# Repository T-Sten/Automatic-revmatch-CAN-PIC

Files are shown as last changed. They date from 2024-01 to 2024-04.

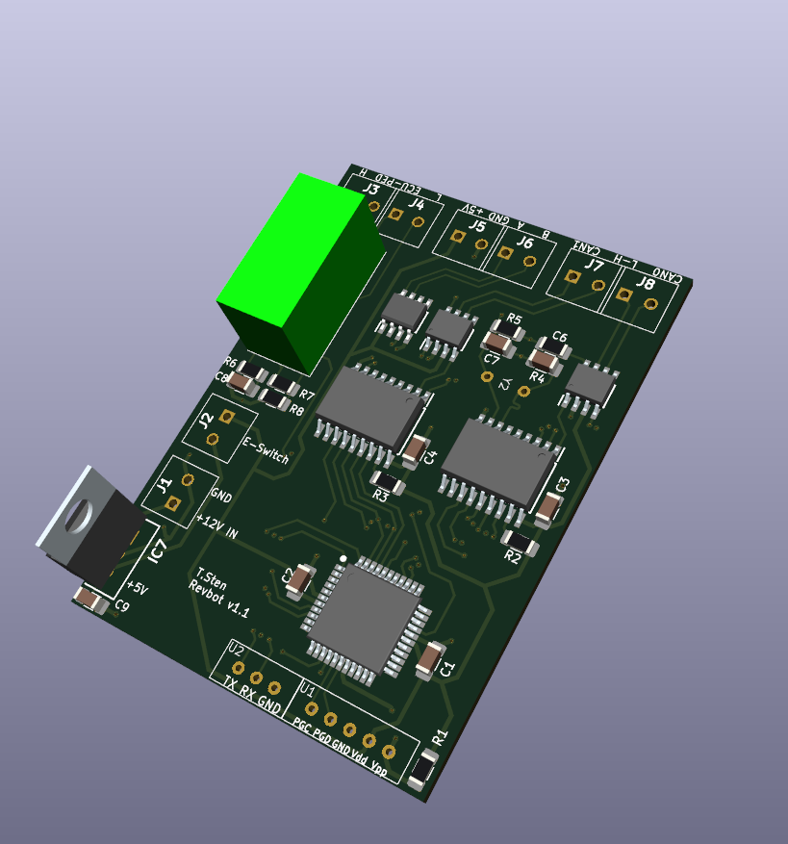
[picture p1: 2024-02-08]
PCB_3D.png

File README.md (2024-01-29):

# OPEL-automatic-revmatch-project

Hi! This is a project on creating a device that by plugging into a car's CAN buses and thottle pedal signals, is able to match the
engine RPMs of the lower gear to the wheel speed during a downshift, known as "Revmatching".
The operation of the device is controlled by a PIC16F877A MCU from Microchip.

### Basic idea
The basic idea is as follows: 
Steering wheel button pressed -> Wait for clutch disengagement -> Raise engine RPM to match the lower gear at the current speed and keep it there
-> Wait for clutch engagement -> Stop.

### CAN bus data
From the 3 CAN buses of my 2005 OPEL Vectra C we are interested in 2 of them: 95kbps low speed bus from where driver input can be read 
(such as steering wheel buttons for activating revmatching mode) and the 500kbps bus from where vehicle telematics data can be read
(such as engine RPM, vehicle speed, clucth state etc.). The vehicles CAN buses will be interfaced with a MCP2515 CAN controller IC
and a MCP2551 CAN transciever IC for each of the 2 buses.

### Controlling the throttle
Throttle is controlled by tapping into the (2) throttle pedal potentiometer output wires and with a signal relay we can disconnect
the thottle pedal outputs and start driving the signal voltage with a capacitor smooothed PWM signal to be interpreted by the ECU.
Throttle value is calculated using PID control.

### Additional features
Additional features of the device include displaying current gear on the dashboard with a 7-segment led and a led array for the current RPM. 
These are driven by 2 8-bit shift registers that are interfaced by the MCU with a single differential pair using a RS485 transciever.
Another feature is "welcome actions" where upon unlocking the car doors, horn is briefly activated 3 times
and high beams flashed. This is done by replicating driver input by sending a CAN frame that corresponds to the activation of their driver controls.

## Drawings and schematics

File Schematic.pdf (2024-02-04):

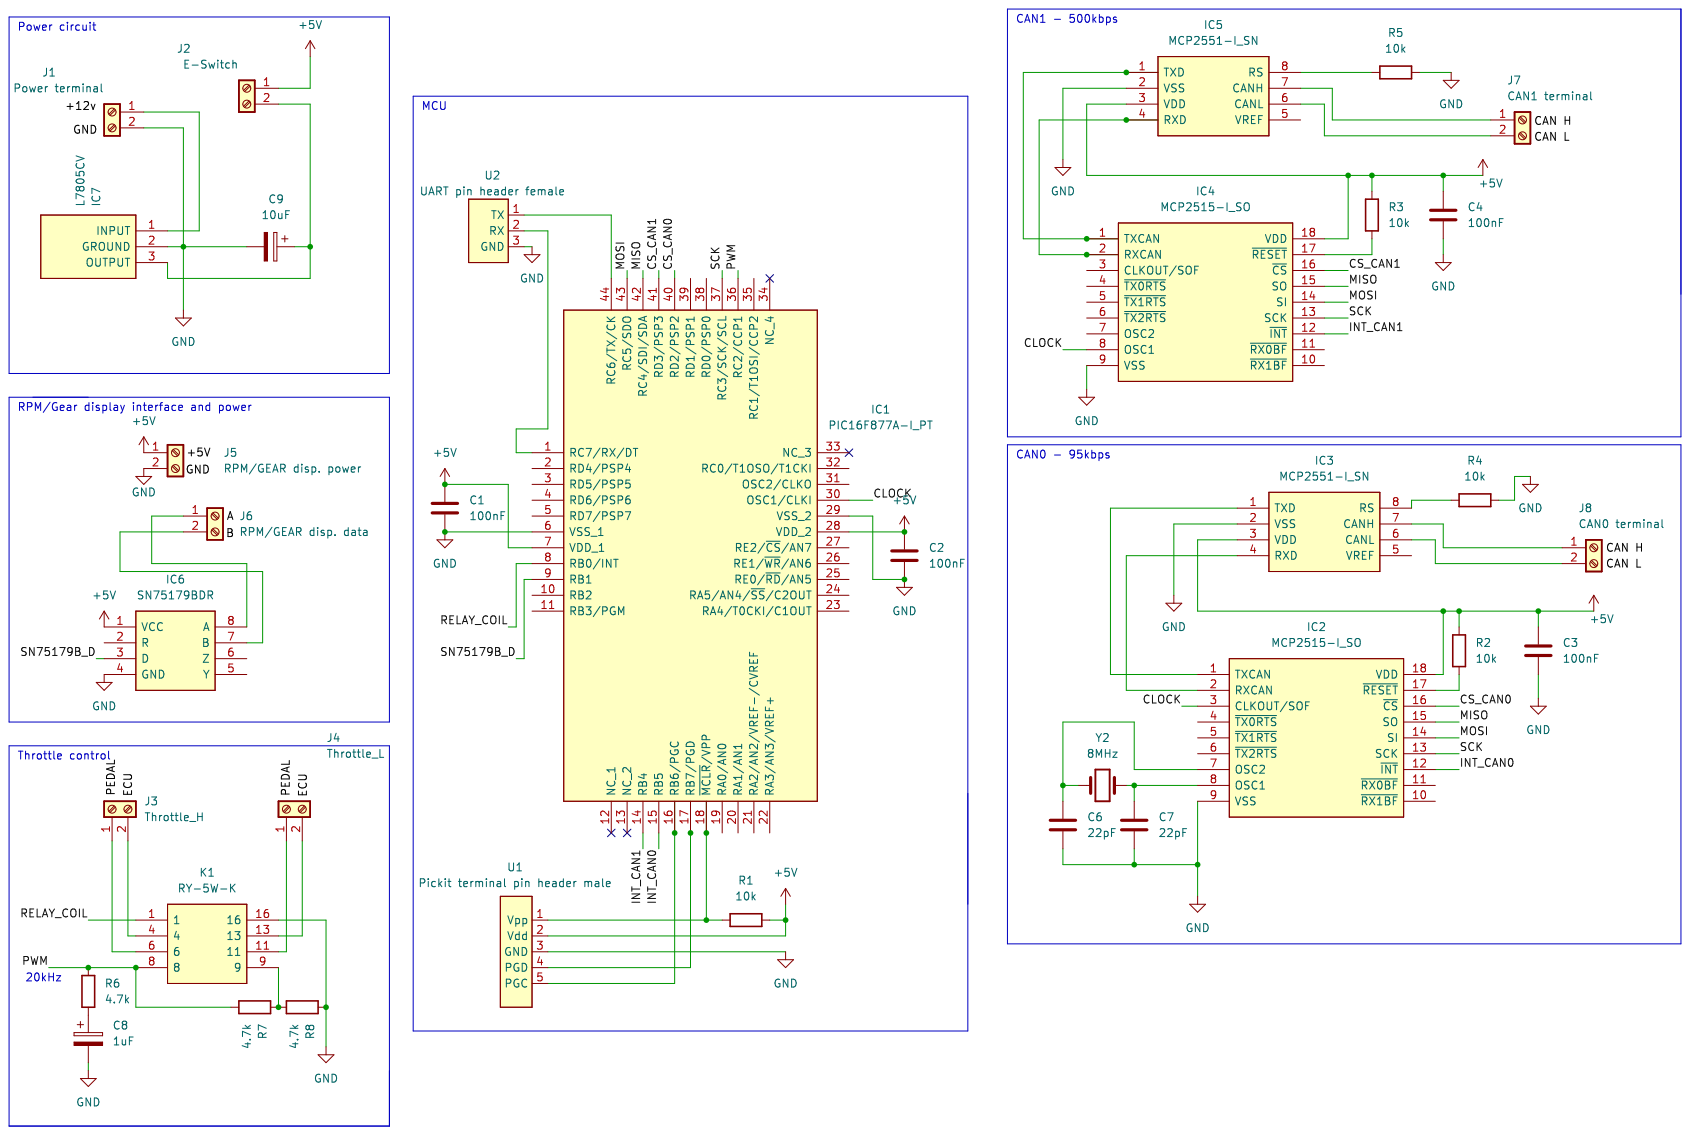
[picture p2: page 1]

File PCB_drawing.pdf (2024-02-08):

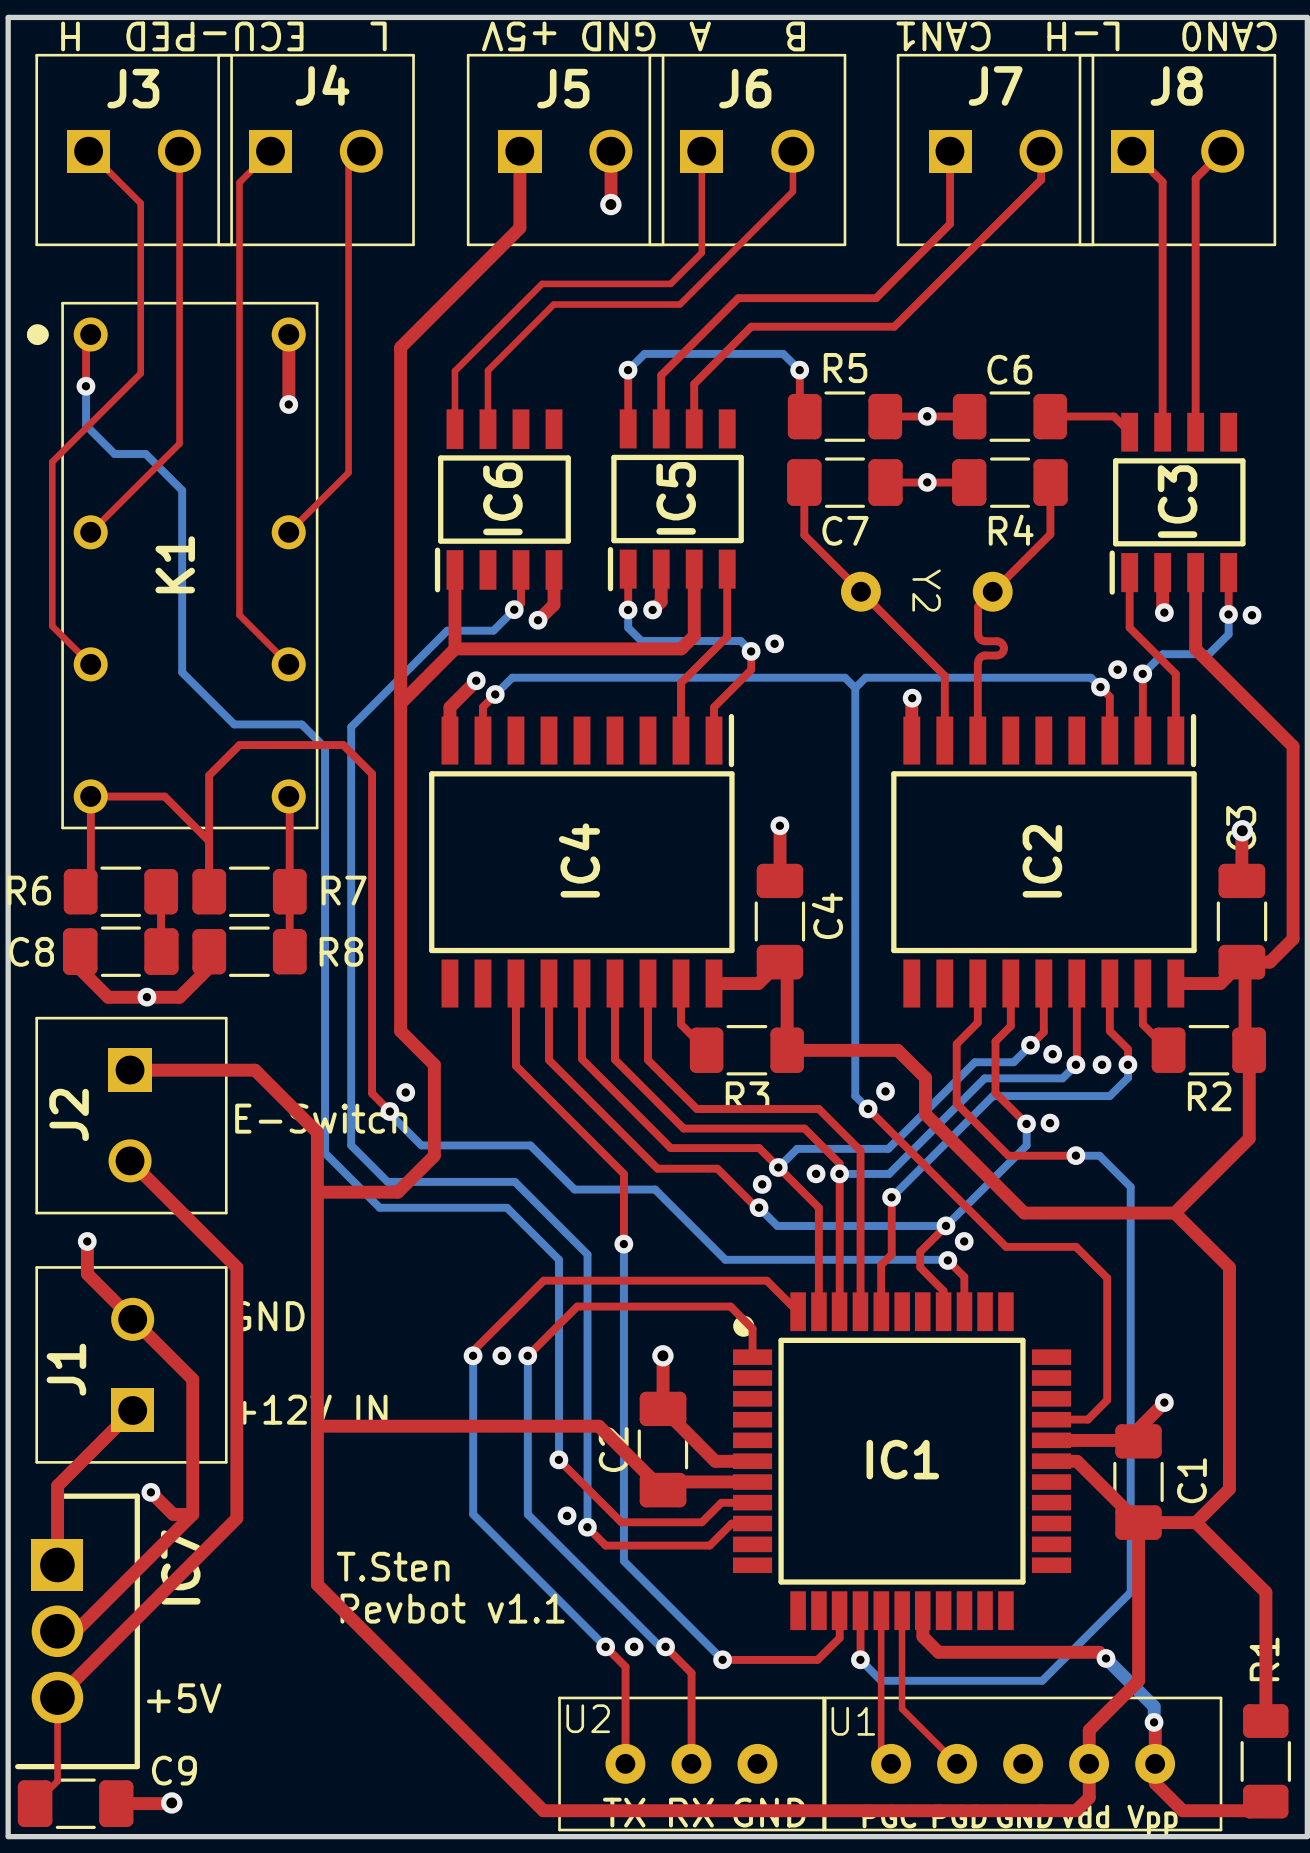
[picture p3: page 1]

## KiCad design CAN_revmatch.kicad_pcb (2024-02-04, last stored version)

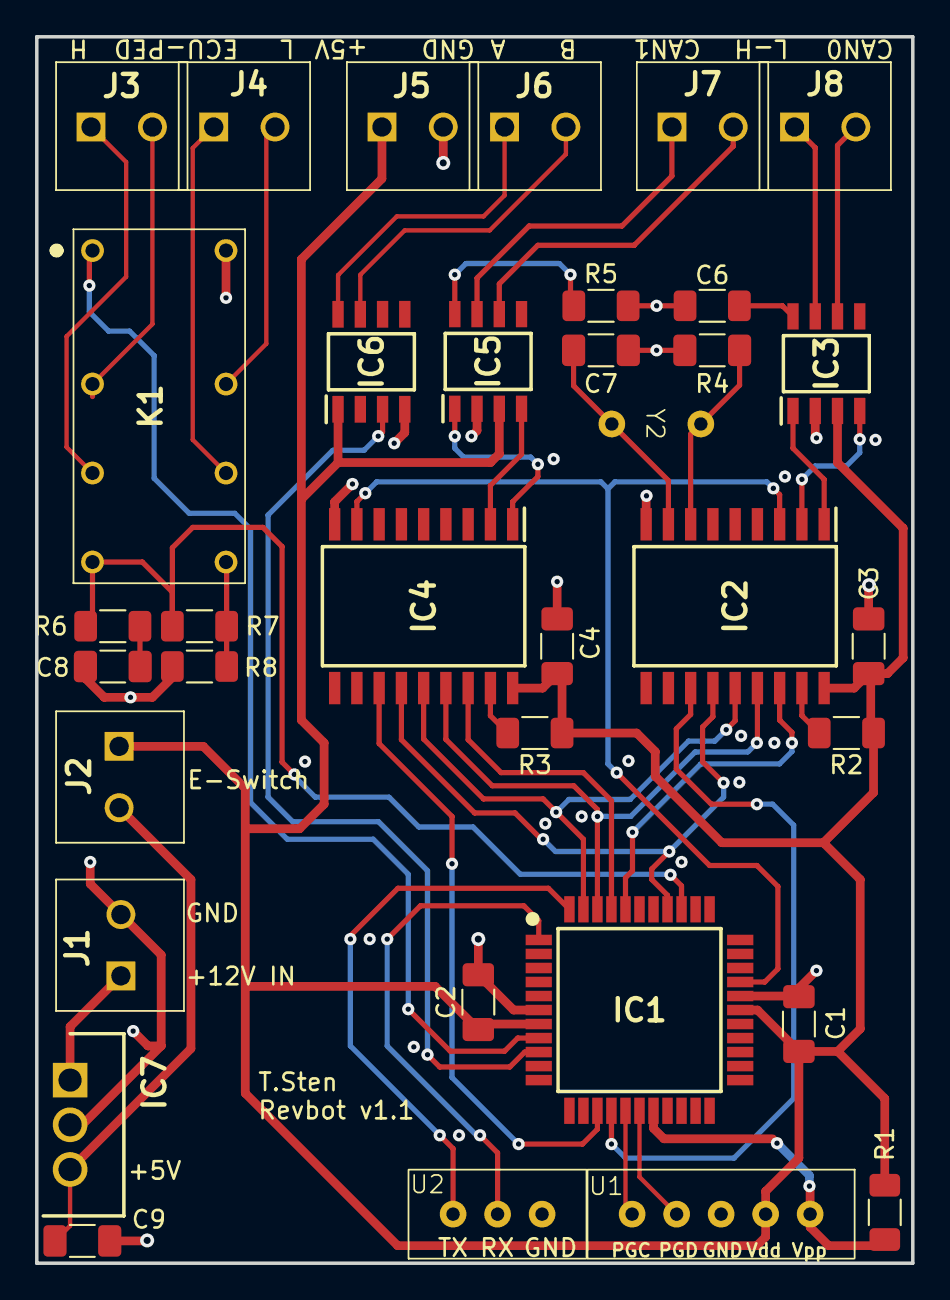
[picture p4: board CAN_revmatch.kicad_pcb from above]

Board: 4 copper layers, 50.0 x 70.0 mm, 35 parts (0 on the bottom side), 42 nets.

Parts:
C1, C2, C3, C4: 100nF; C_1206_3216Metric_Pad1.33x1.80mm_HandSolder
C6, C7: 22pF; C_1206_3216Metric_Pad1.33x1.80mm_HandSolder
C8: 1uF; C_1206_3216Metric_Pad1.33x1.80mm_HandSolder
C9: 10uF; C_1206_3216Metric_Pad1.33x1.80mm_HandSolder
IC1: PIC16F877A-I_PT; PIC16F877A-SOIC-44pin
IC2, IC4: MCP2515-I_SO; MCP2515_SOIC
IC3, IC5: MCP2551-I_SN; MCP2551_SOIC
IC6: SN75179BDR; Transciever_SN75179BDR
IC7: L7805CV
J1: Power terminal; 1888807
J2: E-Switch; 1888807
J3: Throttle_H; 1888807
J4: Throttle_L; 1888807
J5: RPM/GEAR disp. power; 1888807
J6: RPM/GEAR disp. data; 1888807
J7: CAN1 terminal; 1888807
J8: CAN0 terminal; 1888807
K1: RY-5W-K; RY5WK
R1, R2, R3, R4, R5: 10k; R_1206_3216Metric_Pad1.30x1.75mm_HandSolder
R6, R7, R8: 4.7k; R_1206_3216Metric_Pad1.30x1.75mm_HandSolder
U1: Pickit terminal pin header male; PICKIT_terminal
U2: UART pin header female; UART_terminal
Y2: 8MHz; KIDE

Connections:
+5V: C1.1, C2.1, C3.1, C4.1, IC1.7 (VDD_1), IC1.28 (VDD_2), IC2.18 (VDD), IC3.3 (VDD), IC4.18 (VDD), IC5.3 (VDD), IC6.1 (VCC), J2.1, J5.1, R1.2, R2.1, R3.1, U1.2 (Vdd)
/CLOCK: IC1.30 (OSC1/CLKI), IC2.3 (CLKOUT/SOF), IC4.8 (OSC1)
/CS_CAN0: IC1.40 (RD2/PSP2), IC2.16 (~CS)
/CS_CAN1: IC1.41 (RD3/PSP3), IC4.16 (~CS)
/INT_CAN0: IC1.15 (RB5), IC2.12 (~INT)
/INT_CAN1: IC1.14 (RB4), IC4.12 (~INT)
/MISO: IC1.42 (RC4/SDI/SDA), IC2.15 (SO), IC4.15 (SO)
/MOSI: IC1.43 (RC5/SDO), IC2.14 (SI), IC4.14 (SI)
/PWM: IC1.36 (RC2/CCP1), K1.8, R6.1, R7.2
/RELAY_COIL: IC1.8 (RB0/INT), K1.1
/SCK: IC1.37 (RC3/SCK/SCL), IC2.13 (SCK), IC4.13 (SCK)
/SN75179B_D: IC1.9 (RB1), IC6.3 (D)
GND: C1.2, C2.2, C3.2, C4.2, C6.2, C7.2, C8.2, C9.2, IC1.6 (VSS_1), IC1.29 (VSS_2), IC2.9 (VSS), IC3.2 (VSS), IC4.9 (VSS), IC5.2 (VSS), IC6.4 (GND), IC7.2 (GROUND), J1.2, J5.2, K1.16, R4.2, R5.2, R8.1, U1.3 (GND), U2.3 (GND)
unnamed: C8.1, R6.2
unnamed: IC1.16 (RB6/PGC), U1.5 (PGC)
unnamed: IC1.17 (RB7/PGD), U1.4 (PGD)
unnamed: IC1.44 (RC6/TX/CK), U2.1 (TX)
unnamed: IC1.1 (RC7/RX/DT), U2.2 (RX)
unnamed: IC1.18 (~MCLR/VPP), R1.1, U1.1 (Vpp)
unnamed: C7.1, IC2.8 (OSC1), Y2.2
unnamed: C6.1, IC2.7 (OSC2), Y2.1
unnamed: IC2.2 (RXCAN), IC3.4 (RXD)
unnamed: IC2.1 (TXCAN), IC3.1 (TXD)
unnamed: IC2.17 (~RESET), R2.2
unnamed: IC3.7 (CANH), J8.1
unnamed: IC3.6 (CANL), J8.2
unnamed: IC3.8 (RS), R4.1
unnamed: IC4.2 (RXCAN), IC5.4 (RXD)
unnamed: IC4.1 (TXCAN), IC5.1 (TXD)
unnamed: IC4.17 (~RESET), R3.2
unnamed: IC5.7 (CANH), J7.1
unnamed: IC5.6 (CANL), J7.2
unnamed: IC5.8 (RS), R5.1
unnamed: IC6.8 (A), J6.1
unnamed: IC6.7 (B), J6.2
unnamed: IC7.1 (INPUT), J1.1
unnamed: C9.1, IC7.3 (OUTPUT), J2.2
unnamed: J3.1, K1.6
unnamed: J3.2, K1.4
unnamed: J4.1, K1.11
unnamed: J4.2, K1.13
unnamed: K1.9, R7.1, R8.2

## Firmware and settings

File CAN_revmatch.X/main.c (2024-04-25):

/*
 * CAN revmatch PIC16F OPEL Vectra C
 * 
 * File:   main.c
 * Author: Tom Stenvall
 *
 * Created on January 2, 2024, 4:30 PM
 */

#include <xc.h>


#include "config.h"

#include <stdlib.h>
#include <string.h>
//#include <stdio.h> //FOR TESTING (SPRINTF)

#include "spi.h"
#include "mcp2515.h"
#include "PID.h"
#include "UART.h"
#include "dash.h"

#define _XTAL_FREQ 8000000 //"CAN0" MCP2515 SQWOUT will drive the PIC16F877A clock

//HIGH SPEED (BRGH = 1) SPBRG = (Fosc / (16 * BAUDRATE)) - 1
#define SPBRG 4 //100000

#define UART_HIGHSPEED 1

#define RELAY PORTBbits.RB0
#define CAN1_INT PORTBbits.RB4
#define CAN0_INT PORTBbits.RB5

#define SERIAL_BUFFER_SIZE 32

//CAN0 IDs
#define SWHEEL_ID 0x175
#define CENTRLOCKING_ID 0x135
#define PARKSENSOR_ID 0x430

//CAN1 IDs
#define RPM_ID 0x110
#define SPEED_ID 0x410
#define CLUTCH_ID 0x300

/*Good PID values
P 0.06
I 0.00001
D 3.5
*/


//Minimum gear to allow revmatch to
#define MIN_GEAR 2
#define MAX_RPM 5000

#define PWM_DUTY CCPR1L

//Parses can data to global variables and sets driver input flags
void CAN0_ID_handler(Can_frame*);
void CAN1_ID_handler(Can_frame*);

//For interfacing with PC GUI app
void serial_sendCanFrame(uint8_t bus, Can_frame* frame);
void serial_sendConsoleMessage(char *string);
void serial_sendPIDData(uint16_t throttle, uint16_t targetRpm, int16_t *components);
void serial_finishPIDData();
void serial_sendPIDConfig(uint8_t *bytes);

//Sets P, I, D values from the EEPROM
void PID_ini_from_eeprom();

//Estimates current gear from the current speed and RPM global variables,
//returns current gear or 0 for no match
uint8_t get_gear(); 

//Calculates target RPM for next lower gear, current gear as input parameter. 
//Gets current speed from global variable.
uint16_t get_next_target_rpm(uint8_t current_gear);

//PID control for the throttle, returns PWM duty cycle that meets the 1-3.6V HIGH pedal signal
uint8_t get_throttle_pwm(uint16_t target_rpm);

//CAN action sequences, these are all BLOCKING FUNCTIONS!!
void gong(); //Makes a short beep from the instrument cluster
void welcome_action(); //Shortly honks the horn 3 times, turns on highbeams for 2 seconds
void mirror_fold(uint8_t pos); //Folds the mirror up or down for reversing

//Sets idle filters
void CAN_idle_filters();

//For validating of can frame data and serial commands, returns 1 if data is same
uint8_t compareData(uint8_t data_1[],uint8_t data_2[], uint8_t size);


enum MODE{
    IDLE,
    WAIT_CLUTCH,
    REVMATCH,
};

//Serial commands from GUI app
enum serial_command{
    PID_SNIFF_SET,
    SEND,
    FRAME_DUMP_SET,
    ID_DUMP_SET,
    FILTER_SNIFF_START,
    FILTER_SNIFF_END,
    THROTTLE,
    PID_TEST_START,
    PID_TEST_END,
    PID_CONFIG_SET,
    PID_CONFIG_READ
};

//Serial message type to GUI app
typedef enum{
    CANFRAME,
    CONSOLE,
    PID_DATA,
    PID_DATA_END,
    PID_CONFIG
}SERIAL_MESSAGE;

//Tasks set by the GUI app
struct serialTasks{
    uint8_t can_dump_can0 :1;
    uint8_t can_dump_can1 :1;
    
    uint8_t can_sniff :1;
    uint8_t id_dump_can0 : 1;
    uint8_t id_dump_can1 : 1;
    
    uint8_t PID_sniff: 1;
    uint8_t PID_test: 1;
    uint16_t PID_test_targetRpm;
};

//Serial buffer struct
struct serial{
    union{
        struct{
            char sof[3];
            uint8_t len;
            uint8_t command;
            uint8_t data[SERIAL_BUFFER_SIZE - 5];
        };
        uint8_t buffer[SERIAL_BUFFER_SIZE];
    };
    uint8_t received_n;
    uint8_t overflow;
};

union driver_input_flags{
    struct{
        uint8_t sWheelUp : 1;
        uint8_t sWheelDown : 1;
        uint8_t doorsUnlocked :1;
    };
    uint8_t all;  
};

struct modeTasks{
    uint8_t multipleRevMatch : 1;
};

enum MODE mode = IDLE;
union driver_input_flags driverInputFlags;
struct modeTasks modeTasks;
struct serial serial;
struct serialTasks serialTasks;
const char SOF[3] = {'S', 'O', 'F'}; //This is indicates the start of a serial frame to and from the GUI app

uint32_t millis = 0, last_ledsUpdate = 0, last_7segUpdate = 0;

uint16_t current_rpm = 0;
uint8_t clutch_state, current_speed, current_gear;
uint8_t last_gear;

uint8_t dashCleared = 0;

//Create can instances and pointers
Mcp2515 can_0;
Mcp2515 can_1;
Mcp2515* can0 = &can_0;
Mcp2515* can1 = &can_1;

void __interrupt() isr(){
    
    if(CCP2IF){
        CCP2IF = 0;
        millis++;
    }
    
    //Reads UART
    if(RCIF){
        
        if(serial.received_n >= SERIAL_BUFFER_SIZE-2){
            serial.overflow = 1;
            serial.received_n = 0;
        }
        
        serial.buffer[serial.received_n] = RCREG;
        

        if(serial.received_n < 3 && serial.sof[serial.received_n] != SOF[serial.received_n]){
            serial.received_n = 0;
        }
        else{
            serial.received_n++;
        }


        RCIF = 0;            
    }
}

void main(void) {
    
    
    TRISBbits.TRISB0 = 0; //Relay output    
    RELAY = 0;
    
    SPI_ini(SPI_SPEED_FOSC_4);
    
    UART_ini(SPBRG, UART_HIGHSPEED);
    
    TRISBbits.TRISB4 = 1;
    OPTION_REGbits.nRBPU = 0;//Enable pullups
    
    MCP2515_attach(can0, PORT_D, 2);
    MCP2515_attach(can1, PORT_D, 3);
    MCP2515_ini(can0, BUS_SPEED_33KBPS, 1);
    MCP2515_ini(can1, BUS_SPEED_500KBPS, 1);
    
    MCP2515_setmode(can0, MODE_CONFIGURE);
    MCP2515_setmode(can1, MODE_CONFIGURE);
    
    //Set normal operation filters
    CAN_idle_filters();
    
    //Enable specific interrupts to drive the MCP2515 interrupt pin
    MCP2515_interrupt_enable(can0, RX0I | RX1I);   //Interrupts on reception to receive buffer 0 and 1, will wake up and start oscillator on bus activity
    MCP2515_interrupt_enable(can1, RX0I | RX1I);   //Interrupt on reception to receive buffer 0
    
    MCP2515_setmode(can0, MODE_NORMAL);
    MCP2515_setmode(can1, MODE_NORMAL);
    
    MCP2515_setclkout(can0, CLKOUT_1);
    MCP2515_setclkout(can1, CLKOUT_OFF);
    
    PID_ini_from_eeprom();
    
    //PWM INI, uses timer 2
    PR2 = 99; //Period
    CCPR1L = 0; //0% duty - (0-100)
    TRISCbits.TRISC2 = 0; //output
    T2CONbits.T2CKPS = 0; //timer prescale to 0
    T2CONbits.TMR2ON = 1; //enable timer2
    CCP1CONbits.CCP1M = 0b1100; //PWM MODE
    
    //TIMER1 INI (for milliseconds)
    //Prescaler is 0
    T1CONbits.T1CKPS = 0b01; //1:2 prescale from Fosc/4 = 1MHz
    T1CONbits.TMR1ON = 1;
    CCPR2 = 1000; //Interrupt every 1000Hz = every 1ms
    CCP2CONbits.CCP2M = 0b1011; //Compare mode, clears timer 1, sets CCP2IF
    
    //Enable interrupts for millis calculation, enable UART interrupt
    CCP2IE = 1;
    RCIE = 1;
    PEIE = 1;
    GIE = 1;
    
    serial_sendConsoleMessage("Stenvall's Revbot started...");
    
    
    while(1){
        
        
        //PID test started from the PC app
        if(serialTasks.PID_test){
            int16_t components[3];
            uint16_t throttle = PID_calculate(serialTasks.PID_test_targetRpm, current_rpm, millis, components);
            PWM_DUTY = get_throttle_pwm(throttle);
            
            static uint32_t lastPIDserial = 0;
            if(serialTasks.PID_sniff && millis > lastPIDserial + 50){
                lastPIDserial = millis;
                serial_sendPIDData(throttle, serialTasks.PID_test_targetRpm, components);
            }
        }
        
        //Clear dash if no RPM data received after 500 ms
        if(last_ledsUpdate + 500 < millis && !dashCleared){
            dashCleared = 1;
            dash_clear();
        }
        
        //UART intefrace with PC app
        if(serial.received_n > 3 && serial.received_n >= serial.len){   //Check for complete frame
            
            if(serial.command == SEND){
                Can_frame fr_send;
                uint8_t bus_select = serial.data[0];
                fr_send.id = (serial.data[1] << 8) | serial.data[2];
                fr_send.len = serial.data[3];

                uint8_t *data = &serial.data[4];
                for(uint8_t i=0; i < fr_send.len; i++){
                    fr_send.data[i] = data[i];
                }

                if(!bus_select){
                    MCP2515_load_tx(can0, &fr_send, 0);
                    MCP2515_rts(can0, 0);
                }
                else{
                    MCP2515_load_tx(can1, &fr_send, 0);
                    MCP2515_rts(can1, 0);
                }

            }
            else if(serial.command == THROTTLE){

                if(serial.data[0] > 0){
                    RELAY = 1;
                    PWM_DUTY = get_throttle_pwm((uint16_t)serial.data[0]);
                }
                else{
                    RELAY = 0;
                    PWM_DUTY = 0;
                }
            }
            else if(serial.command == PID_SNIFF_SET){
                serialTasks.PID_sniff = serial.data[0];
            }
            else if(serial.command == PID_TEST_START){
                serialTasks.PID_test = 1;
                serialTasks.PID_test_targetRpm = (serial.data[0] << 8) | serial.data[1];
                PID_reset();
                PWM_DUTY = 20;
                RELAY = 1;
            }
            else if(serial.command == PID_TEST_END){
                RELAY = 0;
                serialTasks.PID_test = 0;
                if(serialTasks.PID_sniff){
                    serial_finishPIDData();
                }
            }
            else if(serial.command == FRAME_DUMP_SET){
                if(serial.data[0] | serial.data[1]){
                    serialTasks.can_sniff = 1;
                    
                    MCP2515_disable_filters(can0);
                    MCP2515_disable_filters(can1);
                }
                else{
                    serialTasks.can_sniff = 0;
                    CAN_idle_filters();
                }
                serialTasks.can_dump_can0 = serial.data[0];
                serialTasks.can_dump_can1 = serial.data[1];
            }
            else if(serial.command == ID_DUMP_SET){
                
                serialTasks.id_dump_can0 = serial.data[0];
                serialTasks.id_dump_can1 = serial.data[1];                
                
                //We need to set can_sniff bit so that sending a can frame to serial is even considered
                //NOTE: received Frame BUS will be checked individually for each frame
                if(serialTasks.id_dump_can0 | serialTasks.id_dump_can1){
                    serialTasks.can_sniff = 1;
                    
                    MCP2515_disable_filters(can0);
                    MCP2515_disable_filters(can1);
                }
                else{
                    serialTasks.can_sniff = 0;

                    CAN_idle_filters();
                }
            }
            else if(serial.command == FILTER_SNIFF_START){
                serialTasks.can_sniff = 1;
                
                
                Mcp2515 *bus = can0;
                for(uint8_t i=0; i < 2; i++){
                    
                    uint16_t filterIDs[6];
                    for(uint8_t j=0; j < 6; j++){
                        uint8_t byte_index = 2*j + 6*i;
                        filterIDs[j] = (serial.data[byte_index] << 8) | serial.data[byte_index + 1];
                    }
                    MCP2515_setfilter(bus, filterIDs);
                    bus = can1;
                }
            }
            else if(serial.command == FILTER_SNIFF_END){
                serialTasks.can_sniff = 0;
                
                CAN_idle_filters();
            }
            else if(serial.command == PID_CONFIG_SET){
                union {
                    uint8_t bytes[4];
                    float floatValue;
                } PID[3];
                
                GIE = 0;
                for(uint8_t i=0; i < 3; i++){
                    
                    for(uint8_t j=0; j < 4; j++){
                        uint8_t byte_index = j + i*4;
                        
                        eeprom_write(byte_index, serial.data[byte_index]);
                        while(WR){};
                        EEIF = 0;
                        PID[i].bytes[j] = serial.data[byte_index];
                    }
                }
                GIE = 1;
                PID_ini(PID[0].floatValue, PID[1].floatValue, PID[2].floatValue);
            }
            else if(serial.command == PID_CONFIG_READ){
                uint8_t bytes[12];
                for(uint8_t i=0; i < 12; i++){
                    bytes[i] = eeprom_read(i);
                }
                
                serial_sendPIDConfig(bytes);
            }
            
            serial.received_n = 0;
        }
        
        //CAN interrupt, read can frame
        if(!CAN0_INT | !CAN1_INT){
            
            Mcp2515 *int_can;
            if(!CAN0_INT){
                int_can = can0;
            }
            else if(!CAN1_INT){
                int_can = can1;
            }
            
            Mcp2515_rx_status status = MCP2515_check_rx(int_can);
            if(status.rx0_full | status.rx1_full){
                
                uint8_t receive_buffer;
                MCP_INTERRUPT int_flag;
                if(status.rx0_full){
                    receive_buffer = 0;
                    int_flag = RX0I;
                }
                else{
                    receive_buffer = 1;
                    int_flag = RX1I;
                }
                
                Can_frame frame;
                MCP2515_read_rx(int_can, &frame, receive_buffer);
                MCP2515_interrupt_clear(int_can, int_flag);
                
                if(int_can == can0){
                    CAN0_ID_handler(&frame);
                }
                else{
                    CAN1_ID_handler(&frame);
                }
                
                if(serialTasks.can_sniff){ //GUI app CAN sniffing
                    uint8_t bus;
                    if(int_can == can0){
                        bus = 0;
                    }
                    else{
                        bus = 1;
                    }            
                    
                    if(serialTasks.id_dump_can0 | serialTasks.id_dump_can1){
                        frame.len = 0;  //if we are just dumping the ID set the length to 0
                        if(bus == 0 && serialTasks.id_dump_can0 || bus == 1 && serialTasks.id_dump_can1){ //Check for correct bus
                            serial_sendCanFrame(bus, &frame);
                        }
                    }
                    else if(serialTasks.can_dump_can0 | serialTasks.can_dump_can1){
                        if(bus == 0 && serialTasks.can_dump_can0 || bus == 1 && serialTasks.can_dump_can1){ //Check for correct bus
                            serial_sendCanFrame(bus, &frame);
                        }
                    }
                    else{
                        serial_sendCanFrame(bus, &frame);
                    }
                }
                

            }
        }
        
        switch (mode){
            case IDLE:
                if((driverInputFlags.sWheelUp || driverInputFlags.sWheelDown) && get_gear() > MIN_GEAR && clutch_state < 1){
                    
                    mode = WAIT_CLUTCH;
                    last_gear = get_gear();
                    gong();
                    if(driverInputFlags.sWheelDown){
                        modeTasks.multipleRevMatch = 1;
                    }
                }
                else if(driverInputFlags.doorsUnlocked){
                    welcome_action();
                }
                break;
                
            case WAIT_CLUTCH:
                if(driverInputFlags.sWheelDown | driverInputFlags.sWheelUp){ //Stops waiting for clutch
                    mode = IDLE;
                }
                else if(clutch_state == 1){
                    mode = REVMATCH;
                    PID_reset();
                    PWM_DUTY = 22; //22% = 1V(output) = 0% Throttle
                    RELAY = 1;
                }
                break;
                
            case REVMATCH:
                
                if((driverInputFlags.sWheelUp | driverInputFlags.sWheelDown) || current_rpm > MAX_RPM){ //Stop revmatching immediately
                    RELAY = 0;
                    gong();
                    mode = IDLE;
                }
                else if(clutch_state == 0){ //Clutch released, stop revmatch
                    RELAY = 0;
                    gong();
                    if(modeTasks.multipleRevMatch && get_gear() > MIN_GEAR){ //Check if we need and are allowed to revmatch for antoher gear
                        mode = WAIT_CLUTCH;
                    }
                    else{
                        mode == IDLE;
                        modeTasks.multipleRevMatch = 0;
                    }
                }
                
                if(serialTasks.PID_sniff && mode != REVMATCH){
                    __delay_ms(50);
                    serial_finishPIDData();
                }
                    
                static uint16_t last_rpm;
                static uint8_t last_speed;
                
                if(current_rpm == last_rpm && current_speed == last_speed){ break; } //Since PID is time consuming
                last_rpm = current_rpm;
                last_speed = current_speed;
                
                uint16_t target_rpm = get_next_target_rpm(last_gear);
                
                if(target_rpm > MAX_RPM){ //Don't exceed MAX RPM
                    RELAY = 0;
                    mode = IDLE;
                    gong();
                    break;
                }
                
                int16_t components[3];
                uint16_t throttle = PID_calculate(target_rpm, current_rpm, millis, components);
                PWM_DUTY = get_throttle_pwm(throttle);
                
                if(serialTasks.PID_sniff){ //PID data for GUI app
                    serial_sendPIDData(throttle, target_rpm, components);
                }
                
                break;
        }
        
        driverInputFlags.all = 0;
    }
    return;
}


void serial_startSend(uint8_t len, SERIAL_MESSAGE message){
    UART_send(SOF[0]);
    UART_send(SOF[1]);
    UART_send(SOF[2]);  
    UART_send(len + 5);
    UART_send(message);
}

void serial_finishPIDData(){
    serial_startSend(0, PID_DATA_END);
}

void serial_sendPIDData(uint16_t throttle, uint16_t targetRpm, int16_t *components){
    serial_startSend(9, PID_DATA);
    
    UART_send(current_rpm >> 8); //RPM high
    UART_send(current_rpm); //RPM LOW
    
    UART_send(targetRpm >> 8); //RPM target high
    UART_send(targetRpm); //RPM target LOW
    
    UART_send(throttle >> 8); //Throttle
    UART_send(throttle);
    
    UART_send(components[0]);
    UART_send(components[1]);
    UART_send(components[2]);
}

void serial_sendConsoleMessage(char *string){
    uint8_t len = strlen(string);
    serial_startSend(len, CONSOLE);
    for(uint8_t i=0; i < len; i++){
        UART_send(string[i]);
    }
}

void serial_sendCanFrame(uint8_t bus, Can_frame* frame){
    
    serial_startSend(frame->len + 4, CANFRAME);
    
    UART_send(bus);
    UART_send(frame->id >> 8);
    UART_send(frame->id);
    UART_send(frame->len);
    
    for(uint8_t i=0; i < frame->len; i++){
        UART_send(frame->data[i]);
    }
}

void serial_sendPIDConfig(uint8_t *bytes){
    serial_startSend(12, PID_CONFIG);
    
    for(uint8_t i=0; i < 12; i++){
        UART_send(bytes[i]);
    }
}

uint8_t compareData(uint8_t data_1[],uint8_t data_2[], uint8_t size){
    for(uint8_t i=0; i<size; i++){
        if(data_1[i] != data_2[i]){
            return 0;
        }
    }
    
    return 1;
}

void PID_ini_from_eeprom(){
    union {
        uint8_t bytes[4];
        float floatValue;
    } PID[3];
    
    for(uint8_t i=0; i < 3; i++){

        for(uint8_t j=0; j < 4; j++){
            PID[i].bytes[j] = eeprom_read(j + i*4);
        }
    }
    
    PID_ini(PID[0].floatValue, PID[1].floatValue, PID[2].floatValue);
}

void CAN_idle_filters(){
    
    uint16_t idleFilters[2][6] = 
    {
        {CENTRLOCKING_ID, SWHEEL_ID, PARKSENSOR_ID, 0x00, 0x00, 0x00},
        {CLUTCH_ID, SPEED_ID, RPM_ID, 0x00, 0x00, 0x00}
    };
    
    MCP2515_setfilter(can0, idleFilters[0]);
    MCP2515_setfilter(can1, idleFilters[1]);
}

void CAN0_ID_handler(Can_frame* frame){
    const uint8_t doors_opened[4] = {0x60,0x6,0xC7,0x4D};
    
    switch(frame->id){
        
        case SWHEEL_ID:
            if(frame->data[5] == 0x10 && frame->data[6] == 0x1F){
                driverInputFlags.sWheelUp = 1;
            }
            else if(frame->data[5] == 0x20 && frame->data[6] == 0x01){
                driverInputFlags.sWheelDown = 1;
            }
        break;
        case CENTRLOCKING_ID:
            if(compareData(frame->data, doors_opened, 4)){
                driverInputFlags.doorsUnlocked = 1;
            }
        break;
        case PARKSENSOR_ID:
            if(frame->data[0] == 0x73){
                mirror_fold(1);
            }
            else if(frame->data[0] == 0x03){
                mirror_fold(0);
            }
        break;
    }
}
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

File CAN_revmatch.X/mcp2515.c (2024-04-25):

/*
 * File:   mcp2515.c
 * Author: Tom Stenvall
 *
 * Created on January 8, 2024, 10:45 PM
 */


#include <xc.h>
#include "mcp2515.h"




//Macros for setting the correct SS/CS pin low
#define SS_HIGH *self->_ss_pin_port |= (self->_ss_pin_bitmask);
#define SS_LOW *self->_ss_pin_port &= ~(self->_ss_pin_bitmask);




void MCP2515_attach(Mcp2515* self, SS_PIN_PORT ss_port, uint8_t ss_pin){
    
    //calculate bitmask corresponding to pin number
    self->_ss_pin_bitmask = (uint8_t)(0x01 << ss_pin);
    
    //set corresponding TRIS bit to 0 (output) for SS pin
    switch(ss_port){
        
        case PORT_A:
            TRISA &= ~(self->_ss_pin_bitmask);
            self->_ss_pin_port = &PORTA;
        break;
        
        case PORT_B:
            TRISB &= ~(self->_ss_pin_bitmask);
            self->_ss_pin_port = &PORTB;
        break;
        
        case PORT_C:
            TRISC &= ~(self->_ss_pin_bitmask);
            self->_ss_pin_port = &PORTC;
        break;
        
        case PORT_D:
            TRISD &= ~(self->_ss_pin_bitmask);
            self->_ss_pin_port = &PORTD;
        break;
        
    }
    
    SS_HIGH;
}

void MCP2515_ini(Mcp2515* self, BUS_SPEED bus_speed, uint8_t enable_rollover){
    MCP2515_reset(self);
    
    uint8_t cnf1,cnf2,cnf3;
    
    switch(bus_speed){
        case BUS_SPEED_33KBPS:
            cnf1 = SETTING_33KBPS_CNF1;
            cnf2 = SETTING_33KBPS_CNF2;
            cnf3 = SETTING_33KBPS_CNF3;
            break;
        case BUS_SPEED_95KBPS:
            cnf1 = SETTING_95KBPS_CNF1;
            cnf2 = SETTING_95KBPS_CNF2;
            cnf3 = SETTING_95KBPS_CNF3;
        break;     
        
        case BUS_SPEED_500KBPS:
            cnf1 = SETTING_500KBPS_CNF1;
            cnf2 = SETTING_500KBPS_CNF2;
            cnf3 = SETTING_500KBPS_CNF3;
            break;
    }
    
    MCP2515_set_reg(self, REG_CNF1, cnf1);
    MCP2515_set_reg(self, REG_CNF2, cnf2);
    MCP2515_set_reg(self, REG_CNF3, cnf3);
    
    MCP2515_set_reg(self, REG_RXB0CTRL, 0xFF | (enable_rollover << 2));
    MCP2515_set_reg(self, REG_RXB1CTRL, 0xFF);
}

void MCP2515_reset(Mcp2515* self){
    SS_LOW;
    SPI_transfer(INS_RESET);
    SS_HIGH;
}

uint8_t MCP2515_get_reg(Mcp2515* self, uint8_t reg_address){
    SS_LOW;
    SPI_transfer(INS_READ);
    SPI_transfer(reg_address);
    uint8_t recieved = SPI_transfer(0);
    SS_HIGH;
    return recieved;
}

void MCP2515_set_reg(Mcp2515* self, uint8_t reg_address, uint8_t data){
    SS_LOW;
    SPI_transfer(INS_WRITE);
    SPI_transfer(reg_address);
    SPI_transfer(data);
    SS_HIGH;
}

void MCP2515_load_tx(Mcp2515* self, Can_frame* frame, uint8_t buffer){
    SS_LOW;
    SPI_transfer(INS_LOADTX | (buffer * 2)); 
    
    //Set 11 bit SID (pg 20)
    SPI_transfer((uint16_t)frame->id >> 3);
    SPI_transfer((frame->id & 0b111) << 5);
    
    //Dummy bytes to skip EID registers, since we're here we are sending SID
    SPI_transfer(0);
    SPI_transfer(0);
    
    SPI_transfer(frame->len);
    
    //Set data registers
    for(int i=0;i<frame->len;i++){
        SPI_transfer((uint8_t)frame->data[i]);
    }
    SS_HIGH;
}

void MCP2515_load_tx_ext(Mcp2515* self, Can_extended_id_frame* frame, uint8_t buffer){
    SS_LOW;
    SPI_transfer(INS_LOADTX | (buffer * 4)); //pg 69
    
    //Dummy byte to skip SIDH register
    SPI_transfer(0);
    
    //Set extended id and extended ID bit pg 20,21
    SPI_transfer((frame->id >> 16 & 0b11) | 0b1000);
    SPI_transfer(frame->id >> 8 & 0xFF);
    SPI_transfer(frame->id & 0xFF);
    
    //Set or do not set RTR bit
    if(frame->rtr){
        SPI_transfer(frame->len | 0b1000000);
    }else{
        SPI_transfer(frame->len);
    }

    //Set data registers
    for(int i=0;i<frame->len;i++){
        SPI_transfer((uint8_t)frame->data[i]);
    }
    SS_HIGH;
}

void MCP2515_read_rx(Mcp2515* self, Can_frame* frame, uint8_t buffer){
    
    uint8_t ins;
    if(buffer == 0){ins = INS_READRX;}
    else{ins = INS_READRX | 0b100;}

    SS_LOW;
    SPI_transfer(ins);
    frame->id = (((uint16_t)SPI_transfer(0)) << 3);
    frame->id |= SPI_transfer(0) >> 5;
    
    //skip the extended id registers
    SPI_transfer(0);
    SPI_transfer(0);

    frame->len = SPI_transfer(0);
    
    for(int i=0; i < frame->len; i++){
        frame->data[i] = SPI_transfer(0);
    }
    SS_HIGH;
   
}

Mcp2515_rx_status MCP2515_check_rx(Mcp2515* self){

    SS_LOW;
    SPI_transfer(INS_RXSTATUS);
    uint8_t status_byte = SPI_transfer(0);
    SS_HIGH;
    
    Mcp2515_rx_status status;
    status.rx0_full = (status_byte >> 6) & 0b1;
    status.rx1_full = (status_byte >> 7) & 0b1;
    status.extended_id = (status_byte >> 4) & 0b1;
    status.remote_frame = (status_byte >> 3) & 0b1;
    status.filterhit = (status_byte & 0b111);
    
    
    //Handle rollover condition
    if(status.filterhit > 5){
        status.filterhit -= 5;
        status.rollover = 1;
    }
    else{
        status.rollover = 0;
    }
    
    return status;
}

void MCP2515_rts(Mcp2515* self, uint8_t buffer){
    SS_LOW;
    SPI_transfer(INS_RTS | (0x01 << buffer));
    SS_HIGH;
}

void MCP2515_bitmod(Mcp2515* self, uint8_t reg_address, uint8_t mask, uint8_t data){
    SS_LOW;
    SPI_transfer(INS_BITMOD);
    SPI_transfer(reg_address);
    SPI_transfer(mask);
    SPI_transfer(data);
    SS_HIGH;
}
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

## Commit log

2024-02-04 Added PCB drawing, schematic update
    [CAN_revmatch.kicad_pcb]
2024-02-08 Added pcb layout pdf, fixed via mistake
    [CAN_revmatch.kicad_pcb]
2024-04-25 UART IF added for PC GUI app, corrected can1 bus speed
    [UART.c, main.c, mcp2515.c]
